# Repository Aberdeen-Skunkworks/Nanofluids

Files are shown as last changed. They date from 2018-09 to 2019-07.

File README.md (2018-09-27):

# Nanofluids

Project background:

Moore's Law is a well-known phenomenon that states that in highly dense integrated circuits (IC) the total number of transistors will approximately double every two years. Thermal management becomes unrealistic as the density of transistors with in the IC increase, thus a new challenge has appeared in heat transfer: cooling of nano-scale devices. A more efficient and compact design of heat exchangers is required for advanced nanoelectronics, and one way this can be achieved is through nanofluid technology. A very large enhancement of the thermal conductivity of a base fluid (i.e. water) can be achieved by the addition of highly conductive solid material in the form of nanoparticles. The mechanics of this enhancement have generally fallen into the classical/continuum bounds given by series and parallel resistances. These bounds are defined by two separate phases of the solid nanoparticles and the liquid medium and the arrangement of the nanoparticles with in the medium. But a small number of experimental result do not fall into these bounds such as helium and hydrogen gas mixtures or the theoretical hard sphere model, which instead exhibit conductivity enhancements above the parallel bounds and dehancement below the series bounds. This project is to explore this phenomena, both experimentally and theoretically, and to attempt to model its effects.

Project Objectives

• Review nanofluids and their history in thermal conductivity enhancement. This includes describing what models have already been used to approximate their behaviour and critically review their applicability.

•	Construct a Transient Heated Wire cell for the testing of liquid and gas mixture thermal conductivities and use this data to explore the anomalous heat transfer in nanofluids and gas mixtures which have similar dimensional properties to nanofluid systems.

• Perform molecular simulations of thermal conduction to confirm if transient effects in the thermal conductivity, possible at small time/length scales, dominate conduction. These simulations may be molecular dynamics simulations using DynamO, or coupled kinetic theory-hydrodynamics simulations using code developed by Craig Moir, a PhD student at Aberdeen

•	Explore new heat exchanger designs which incorporate any time-dependent anomalous phenomena

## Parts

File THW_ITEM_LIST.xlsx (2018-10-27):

ASAD THW ITEM LIST
ITEM | QUANTITY REQUIRED | LINK
PT sensor 1206 | 6 | https://uk.farnell.com/vishay/pts120601b1k00p100/thermistor-pts-ptc-1k-1206/dp/1560921?mckv=sxhpFhfmc_dc|pcrid|148077176083|kword|pts120601b1k00p100|match|p|plid||slid||product||pgrid|15046885808|ptaid|kwd-10806921207|&CMP=KNC-GUK-GEN-SKU-MDC&gclid=CjwKCAjwx7DeBRBJEiwA9MeX_N3hO8ln7X4XWF5Pzf3dMA8ltC6UXv4zSTR2f6gVfCRME1TUpfP6mxoC_D4QAvD_BwE
CAT6 RJ45 Female socket | 5 | https://uk.rs-online.com/web/p/rj45-connectors/7418528/
Potentiometers | 4 | https://uk.rs-online.com/web/p/trimmer-resistors/1442194/
Percise Resistor | 1 | https://uk.rs-online.com/web/p/surface-mount-fixed-resistors/1372749/
Plat Wire | ? | ?
Cu Wire | ? | ?

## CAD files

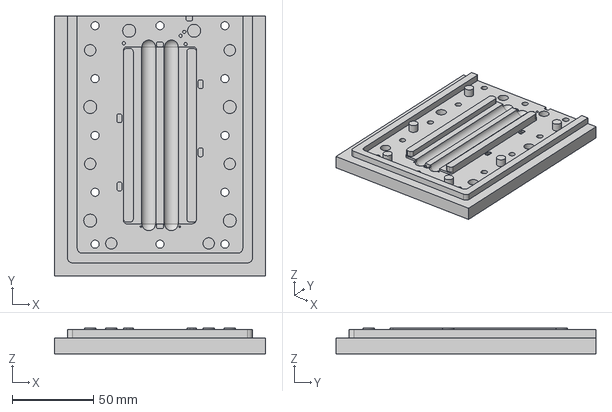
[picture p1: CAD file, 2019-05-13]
THW_Design/CellDesign_1.step
130.0 x 160.0 x 16.0 mm

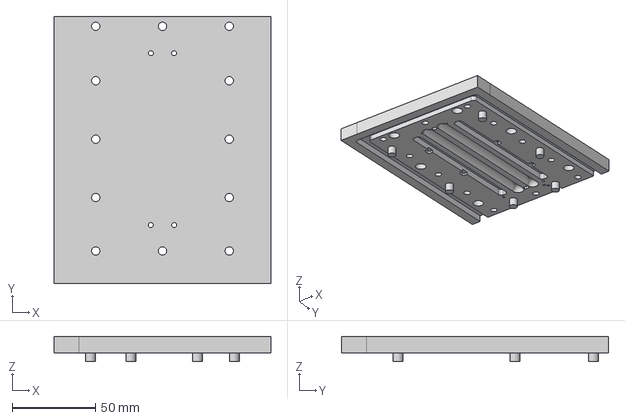
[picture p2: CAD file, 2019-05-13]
THW_Design/CellDesign_2.step
130.0 x 160.0 x 15.0 mm

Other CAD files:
THW_Design/Cell2test.step
THW_Design/test2.step
THW_Design/test.f3d

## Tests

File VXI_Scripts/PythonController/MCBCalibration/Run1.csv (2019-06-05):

Legend:
1-P = | Untitled 1 Process
1-A = | Untitled 1 Ambient
2-P = | Untitled 2 Process
2-A = | Untitled 2 Ambient
Interval: | 10 | Seconds
DataPoint | LogDate | LogTime | 1-P °C | 1-A °C | 2-P °C | 2-A °C
0 | 27/05/2019 | 14:01:39 | 46.8 | 18.0 | 26.8 | 19.5
1 | 27/05/2019 | 14:01:49 | 48.4 | 18.0 | 27.6 | 19.5
2 | 27/05/2019 | 14:01:59 | 49.7 | 18.0 | 28.3 | 19.5
3 | 27/05/2019 | 14:02:09 | 50.9 | 17.9 | 29.0 | 19.5
4 | 27/05/2019 | 14:02:19 | 51.9 | 17.9 | 29.6 | 19.5
5 | 27/05/2019 | 14:02:29 | 52.7 | 17.9 | 30.2 | 19.5
6 | 27/05/2019 | 14:02:39 | 53.5 | 17.9 | 30.8 | 19.5
7 | 27/05/2019 | 14:02:49 | 54.1 | 17.9 | 31.4 | 19.5
8 | 27/05/2019 | 14:02:59 | 54.6 | 17.9 | 32.0 | 19.5
9 | 27/05/2019 | 14:03:09 | 55.1 | 17.9 | 32.5 | 19.5
10 | 27/05/2019 | 14:03:19 | 55.5 | 17.9 | 33.0 | 19.5
11 | 27/05/2019 | 14:03:29 | 55.9 | 17.9 | 33.5 | 19.5
12 | 27/05/2019 | 14:03:39 | 56.2 | 17.9 | 34.0 | 19.4
13 | 27/05/2019 | 14:03:49 | 56.4 | 17.9 | 34.4 | 19.4
14 | 27/05/2019 | 14:03:59 | 56.7 | 17.9 | 34.8 | 19.4
15 | 27/05/2019 | 14:04:09 | 56.9 | 17.9 | 35.3 | 19.4
16 | 27/05/2019 | 14:04:19 | 56.9 | 17.8 | 35.7 | 19.4
17 | 27/05/2019 | 14:04:29 | 57.1 | 17.8 | 36.1 | 19.4
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

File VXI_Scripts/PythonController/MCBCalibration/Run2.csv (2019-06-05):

Legend:
1-P = | Untitled 1 Process
1-A = | Untitled 1 Ambient
2-P = | Untitled 2 Process
2-A = | Untitled 2 Ambient
Interval: | 10 | Seconds
DataPoint | LogDate | LogTime | 1-P °C | 1-A °C | 2-P °C | 2-A °C
0 | 28/05/2019 | 17:16:49 | 21.4 | 17.2 | 21.8 | 18.9
1 | 28/05/2019 | 17:16:59 | 21.4 | 17.2 | 21.8 | 18.9
2 | 28/05/2019 | 17:17:10 | 21.4 | 17.2 | 21.8 | 18.9
3 | 28/05/2019 | 17:17:20 | 21.4 | 17.2 | 21.8 | 18.9
4 | 28/05/2019 | 17:17:30 | 21.4 | 17.2 | 21.8 | 18.9
5 | 28/05/2019 | 17:17:40 | 21.4 | 17.2 | 21.8 | 18.9
6 | 28/05/2019 | 17:17:50 | 21.4 | 17.2 | 21.8 | 18.9
7 | 28/05/2019 | 17:18:00 | 21.5 | 17.2 | 21.8 | 18.9
8 | 28/05/2019 | 17:18:10 | 21.4 | 17.2 | 21.8 | 18.9
9 | 28/05/2019 | 17:18:20 | 21.4 | 17.2 | 21.8 | 18.9
10 | 28/05/2019 | 17:18:30 | 21.4 | 17.2 | 21.8 | 18.9
11 | 28/05/2019 | 17:18:40 | 21.4 | 17.2 | 21.8 | 18.9
12 | 28/05/2019 | 17:18:50 | 21.4 | 17.2 | 21.8 | 18.9
13 | 28/05/2019 | 17:19:00 | 21.4 | 17.2 | 21.9 | 18.9
14 | 28/05/2019 | 17:19:10 | 21.4 | 17.2 | 21.9 | 18.9
15 | 28/05/2019 | 17:19:20 | 21.4 | 17.2 | 21.8 | 18.9
16 | 28/05/2019 | 17:19:30 | 21.4 | 17.2 | 21.8 | 18.9
17 | 28/05/2019 | 17:19:40 | 21.4 | 17.2 | 21.8 | 18.9
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

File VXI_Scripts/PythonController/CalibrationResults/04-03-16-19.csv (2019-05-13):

# | SW | SW (t) | LW | LW (t) | TP (ohm) | Temp Probe (*C) | TP (t) | PT_6 (ohm) | PT_6 (*C) | PT_6 (t) | PT_1 (ohm) | PT_1 (*C) | PT_1 (t) | PT_2 (ohm) | PT_2 (*C) | PT_2 (t) | PT_3 (ohm) | PT_3 (*C) | PT_3 (t) | PT_4 (ohm) | PT_4 (*C) | PT_4 (t) | PT_5 (ohm) | PT_5 (*C) | PT_5 (t)
0 | 38.23242 | 16:19:18.152614 | 56.04883 | 16:19:18.217416 | 107.5488 | 19.371097546592672 | 16:19:18.284237 | 1178.779 | 20.68036856046361 | 16:19:18.351057 | 1179.959 | 20.92157884107316 | 16:19:18.419874 | 1170.195 | 18.921392684463715 | 16:19:18.488691 | 1171.275 | 19.143113850957572 | 16:19:18.555551 | 1233.301 | -312.6102721135922 | 16:19:18.621336 | 1179.891 | 20.907682426459267 | 16:19:18.687160
1 | 38.23047 | 16:19:18.773963 | 56.04492 | 16:19:18.839751 | 107.5449 | 19.361061471522248 | 16:19:18.907570 | 1178.785 | 20.68159541119711 | 16:19:18.974446 | 1179.967 | 20.92321368253006 | 16:19:19.046200 | 1170.203 | 18.923035504072534 | 16:19:19.114018 | 1171.283 | 19.14475578300881 | 16:19:19.182836 | 1233.311 | -312.609460367523 | 16:19:19.249656 | 1179.9 | 20.909521684749542 | 16:19:19.320731
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

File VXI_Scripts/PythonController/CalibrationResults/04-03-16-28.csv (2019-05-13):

# | SW | SW (t) | LW | LW (t) | TP (ohm) | Temp Probe (*C) | TP (t) | PT_6 (ohm) | PT_6 (*C) | PT_6 (t) | PT_1 (ohm) | PT_1 (*C) | PT_1 (t) | PT_2 (ohm) | PT_2 (*C) | PT_2 (t) | PT_3 (ohm) | PT_3 (*C) | PT_3 (t) | PT_4 (ohm) | PT_4 (*C) | PT_4 (t) | PT_5 (ohm) | PT_5 (*C) | PT_5 (t)
0 | 38.24414 | 16:28:49.439085 | 56.07031 | 16:28:49.504885 | 107.5762 | 19.441608229594856 | 16:28:49.573749 | 1179.313 | 20.78954395067271 | 16:28:49.640546 | 1180.377 | 21.006990613046685 | 16:28:49.713327 | 1170.687 | 19.02241385323105 | 16:28:49.784138 | 1171.807 | 19.252288027551632 | 16:28:49.849962 | 1233.842 | -312.5663621480739 | 16:28:49.916783 | 1180.449 | 21.021700899217958 | 16:28:49.986618
1 | 38.24609 | 16:28:50.070376 | 56.06836 | 16:28:50.136197 | 107.5801 | 19.451644538738034 | 16:28:50.206010 | 1179.318 | 20.79056605526184 | 16:28:50.272880 | 1180.389 | 21.009442363919703 | 16:28:50.341647 | 1170.693 | 19.023645665186695 | 16:28:50.408500 | 1171.807 | 19.252288027551632 | 16:28:50.474297 | 1233.855 | -312.565307148045 | 16:28:50.540390 | 1180.453 | 21.022518121923166 | 16:28:50.610962
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

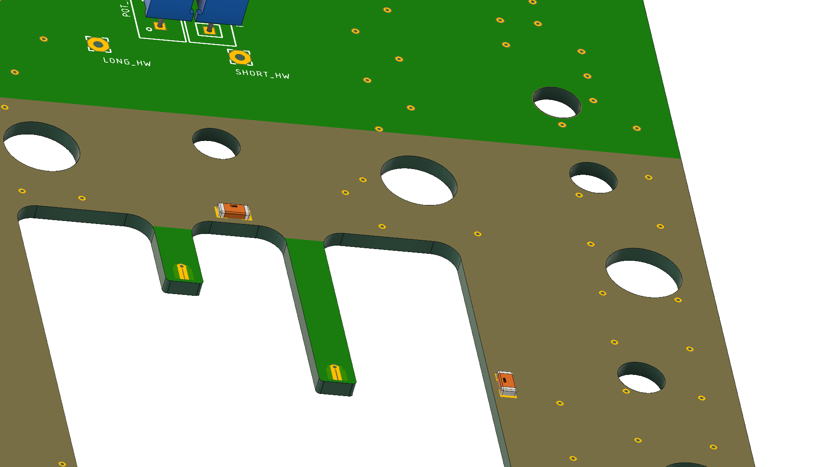
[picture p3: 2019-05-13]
THW_Design/Test v24.png

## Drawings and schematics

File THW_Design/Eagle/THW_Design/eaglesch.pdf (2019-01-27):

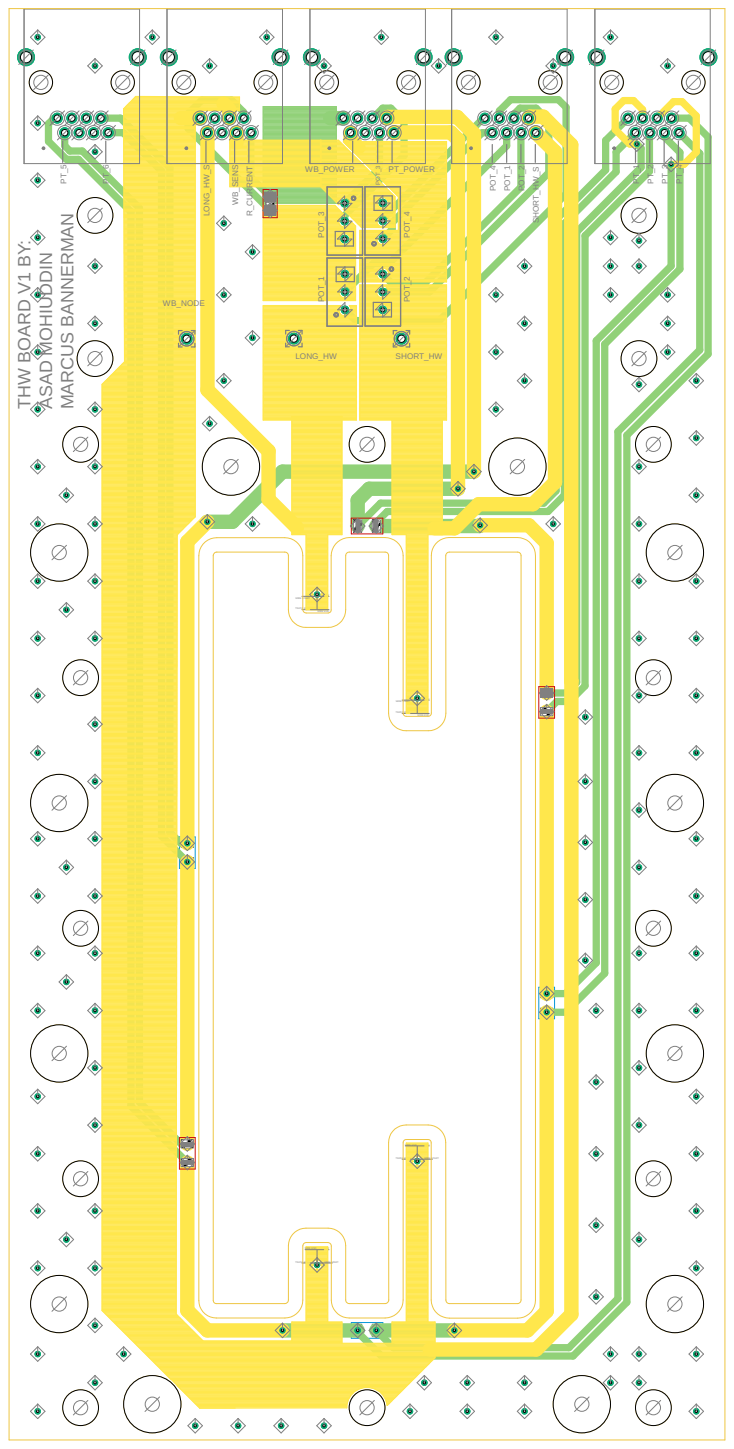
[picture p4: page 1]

WB_NODE

LONG_HW | SHORT_HW

WIRE END WIRE START

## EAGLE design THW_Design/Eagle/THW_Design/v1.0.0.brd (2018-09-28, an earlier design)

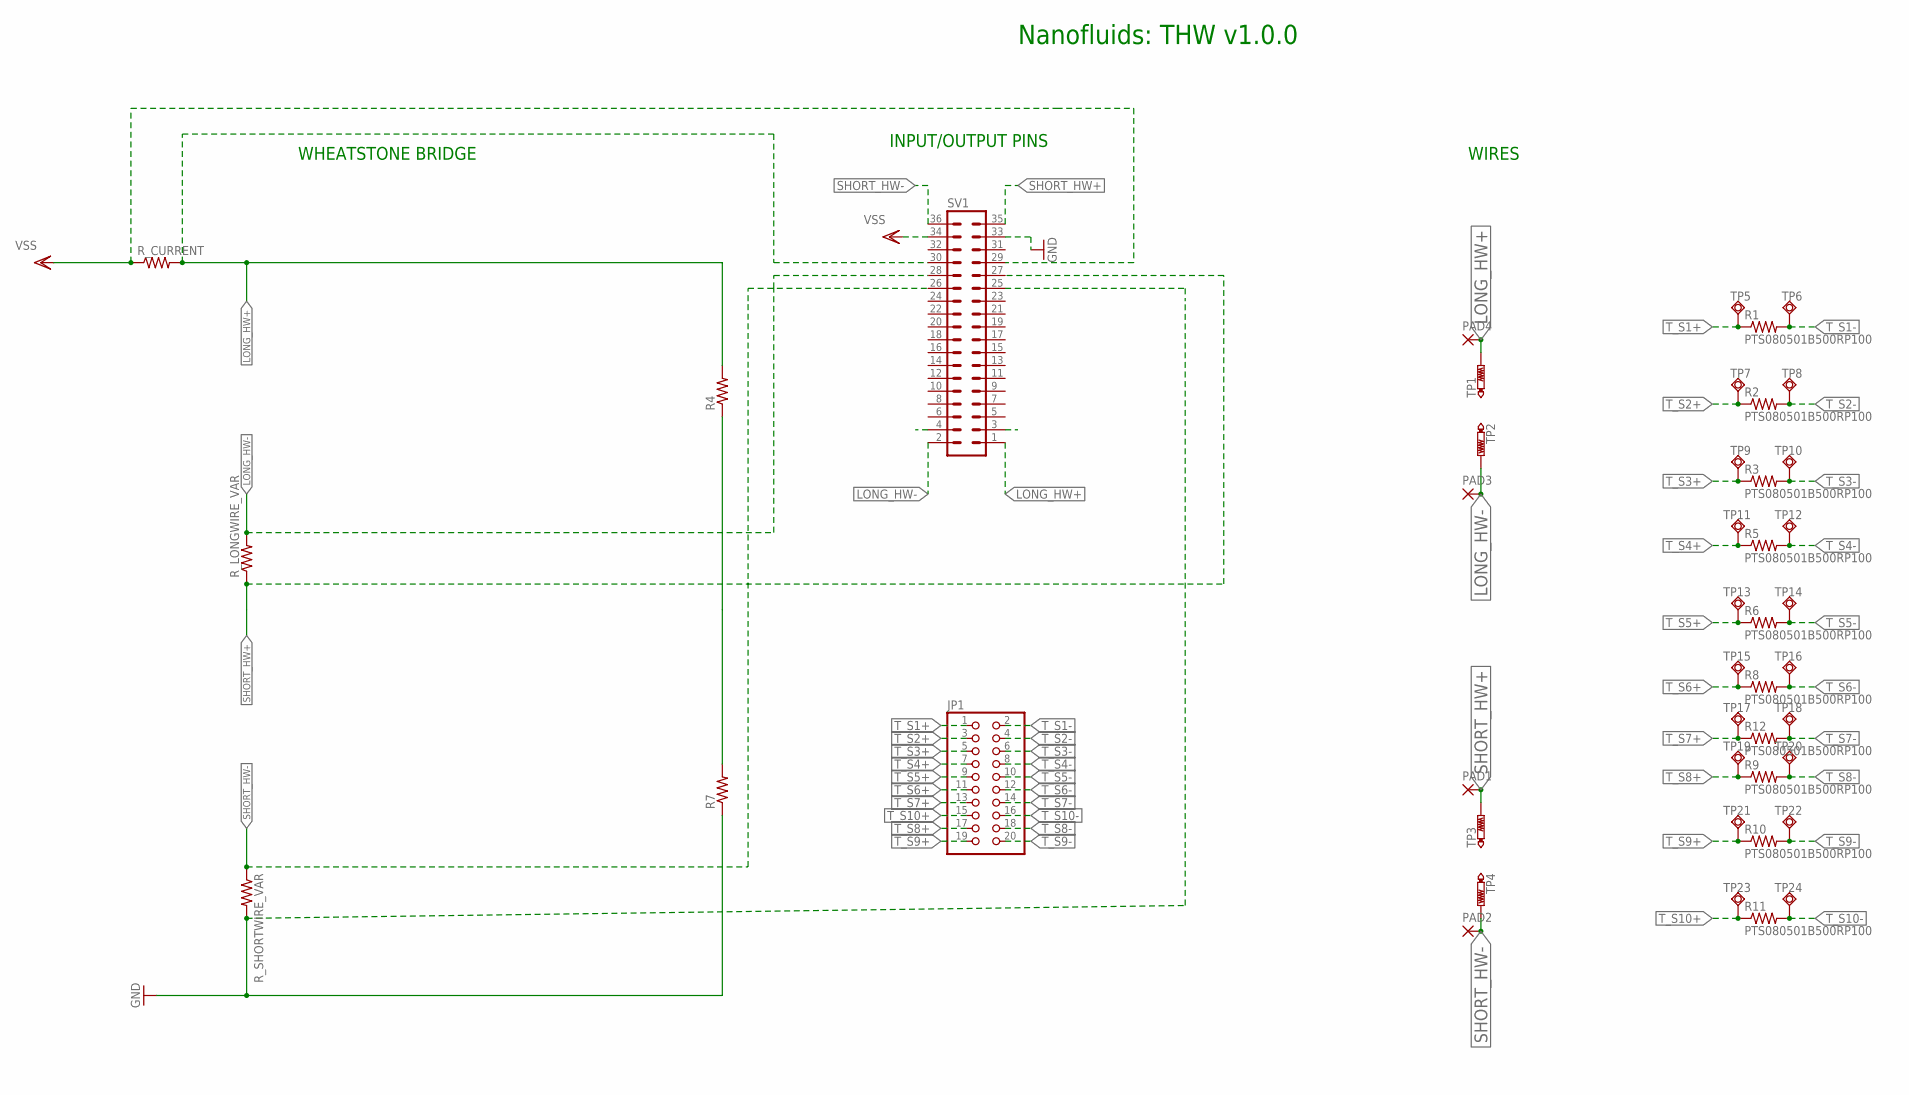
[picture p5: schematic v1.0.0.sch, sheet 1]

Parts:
JP1: PINHD-2X10; 2X10
PAD1, PAD2, PAD3, PAD4: SMD5; SMD2,54-5,08
R1, R2, R3, R5, R6, R8, R9, R10, R11, R12: PTS080501B500RP100; RESC2012X60
R4, R7: R-US_M0805; M0805
R_CURRENT: R-US_M0805; M0805
R_LONGWIRE_VAR: R-US_M0805; M0805
R_SHORTWIRE_VAR: R-US_M0805; M0805
SV1: MA18-2
TP1, TP2, TP3, TP4: PTR1TP20R; TP20R
TP5, TP6, TP7, TP8, TP9, TP10, TP11, TP12, TP13, TP14, TP15, TP16, TP17, TP18, TP19, TP20, TP21, TP22, TP23, TP24: TPSQTP09SQ; TP09SQ

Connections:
GND: R7.1, R_SHORTWIRE_VAR.2, SV1.25, SV1.33
LONG_HW+: PAD4.1, R4.2, R_CURRENT.2, SV1.1, SV1.30, TP1.TP
LONG_HW-: PAD3.1, R_LONGWIRE_VAR.2, SV1.2, SV1.28, TP2.TP
unnamed: R4.1, R7.2
SHORT_HW+: PAD1.1, R_LONGWIRE_VAR.1, SV1.27, SV1.35, TP3.TP
SHORT_HW-: PAD2.1, R_SHORTWIRE_VAR.1, SV1.26, SV1.36, TP4.TP
T_S1+: JP1.1, R1.1, TP5.TP
T_S1-: JP1.2, R1.2, TP6.TP
T_S2+: JP1.3, R2.1, TP7.TP
T_S2-: JP1.4, R2.2, TP8.TP
T_S3+: JP1.5, R3.1, TP9.TP
T_S3-: JP1.6, R3.2, TP10.TP
T_S4+: JP1.7, R5.1, TP11.TP
T_S4-: JP1.8, R5.2, TP12.TP
T_S5+: JP1.9, R6.1, TP13.TP
T_S5-: JP1.10, R6.2, TP14.TP
T_S6+: JP1.11, R8.1, TP15.TP
T_S6-: JP1.12, R8.2, TP16.TP
T_S7+: R12.1, TP17.TP
T_S7-: JP1.14, R12.2, TP18.TP
T_S8+: JP1.17, R9.1, TP19.TP
T_S8-: JP1.18, R9.2, TP20.TP
T_S9+: JP1.19, R10.1, TP21.TP
T_S9-: JP1.20, R10.2, TP22.TP
T_S10+: JP1.15, R11.1, TP23.TP
T_S10-: JP1.16, R11.2, TP24.TP
VSS: R_CURRENT.1, SV1.29, SV1.34

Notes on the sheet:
Nanofluids: THW v1.0.0
WHEATSTONE BRIDGE
WIRES
INPUT/OUTPUT PINS

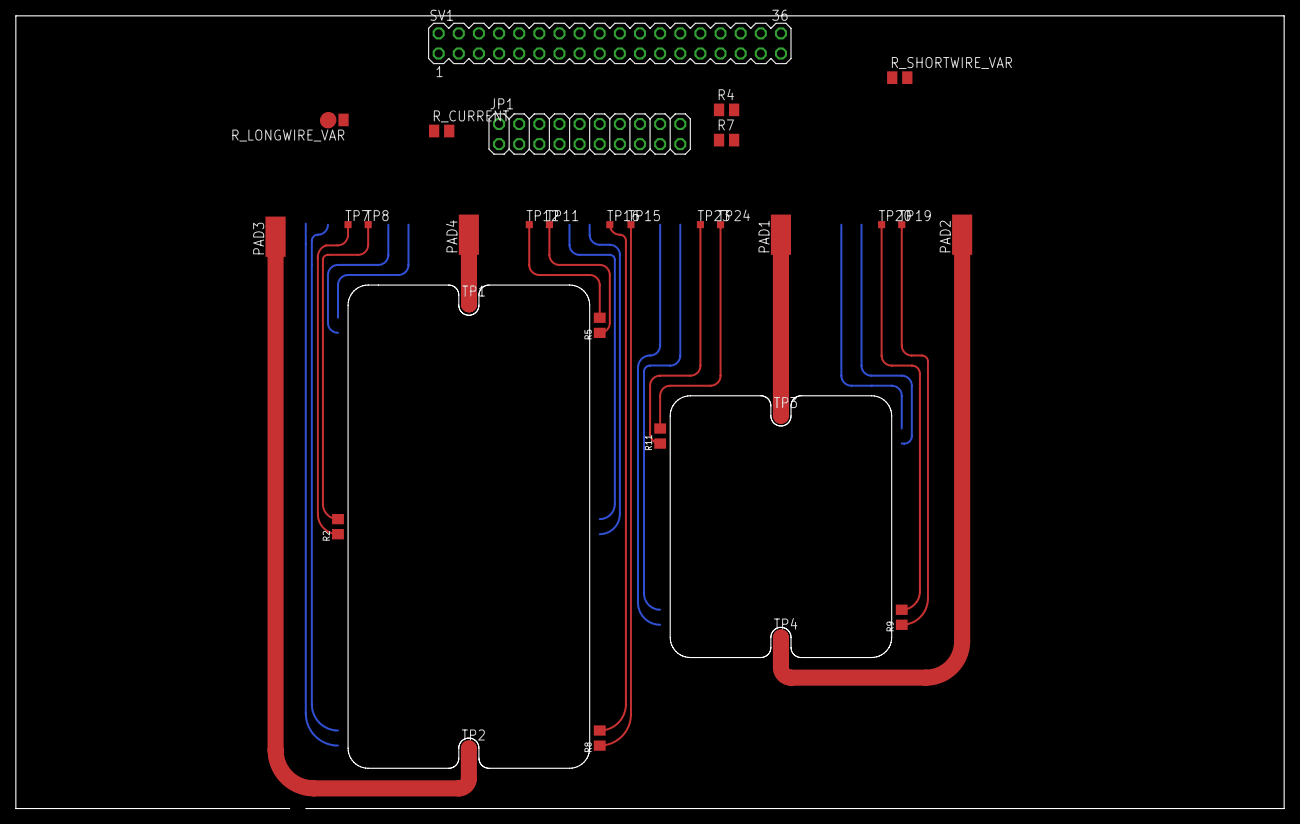
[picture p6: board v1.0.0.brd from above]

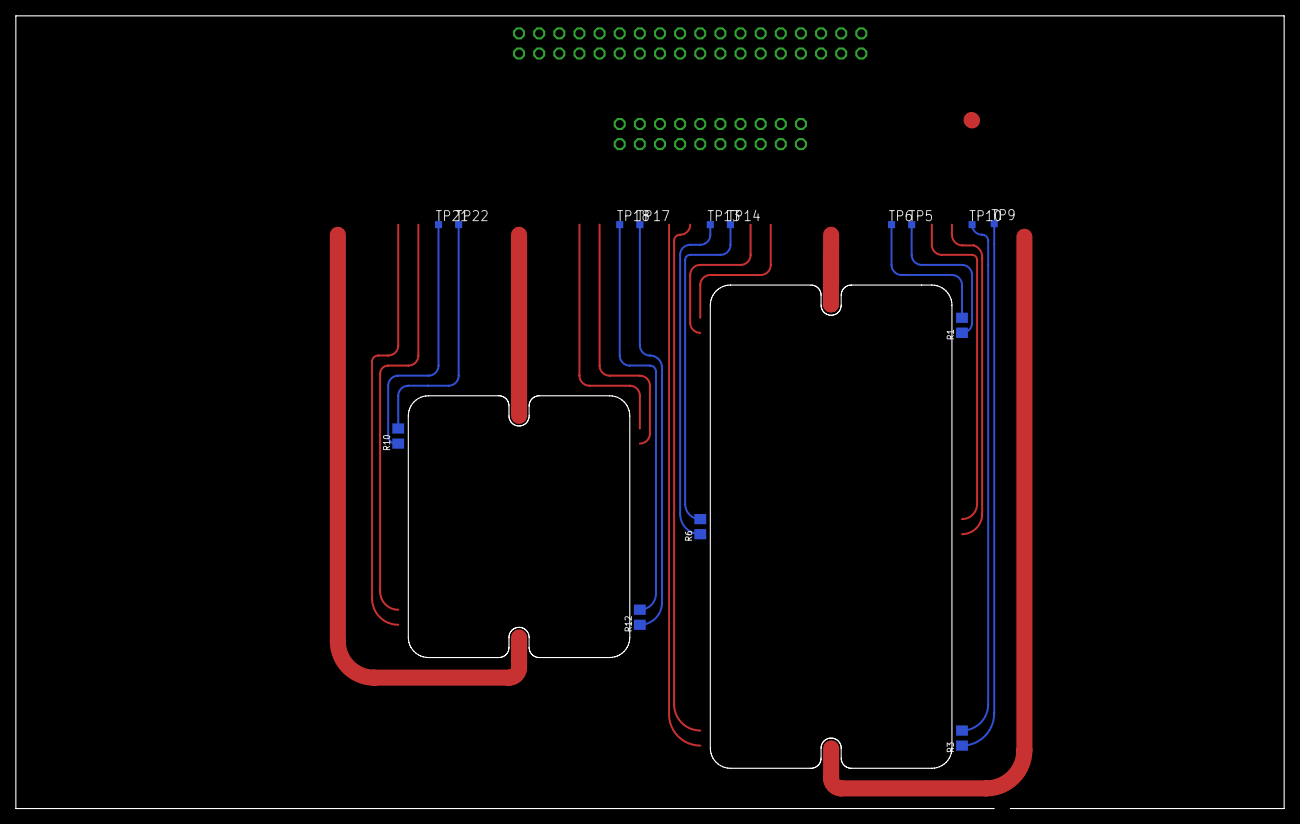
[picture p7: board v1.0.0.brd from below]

Board: 3 copper layers, 160.0 x 100.0 mm, 45 parts (15 on the bottom side), 27 nets.

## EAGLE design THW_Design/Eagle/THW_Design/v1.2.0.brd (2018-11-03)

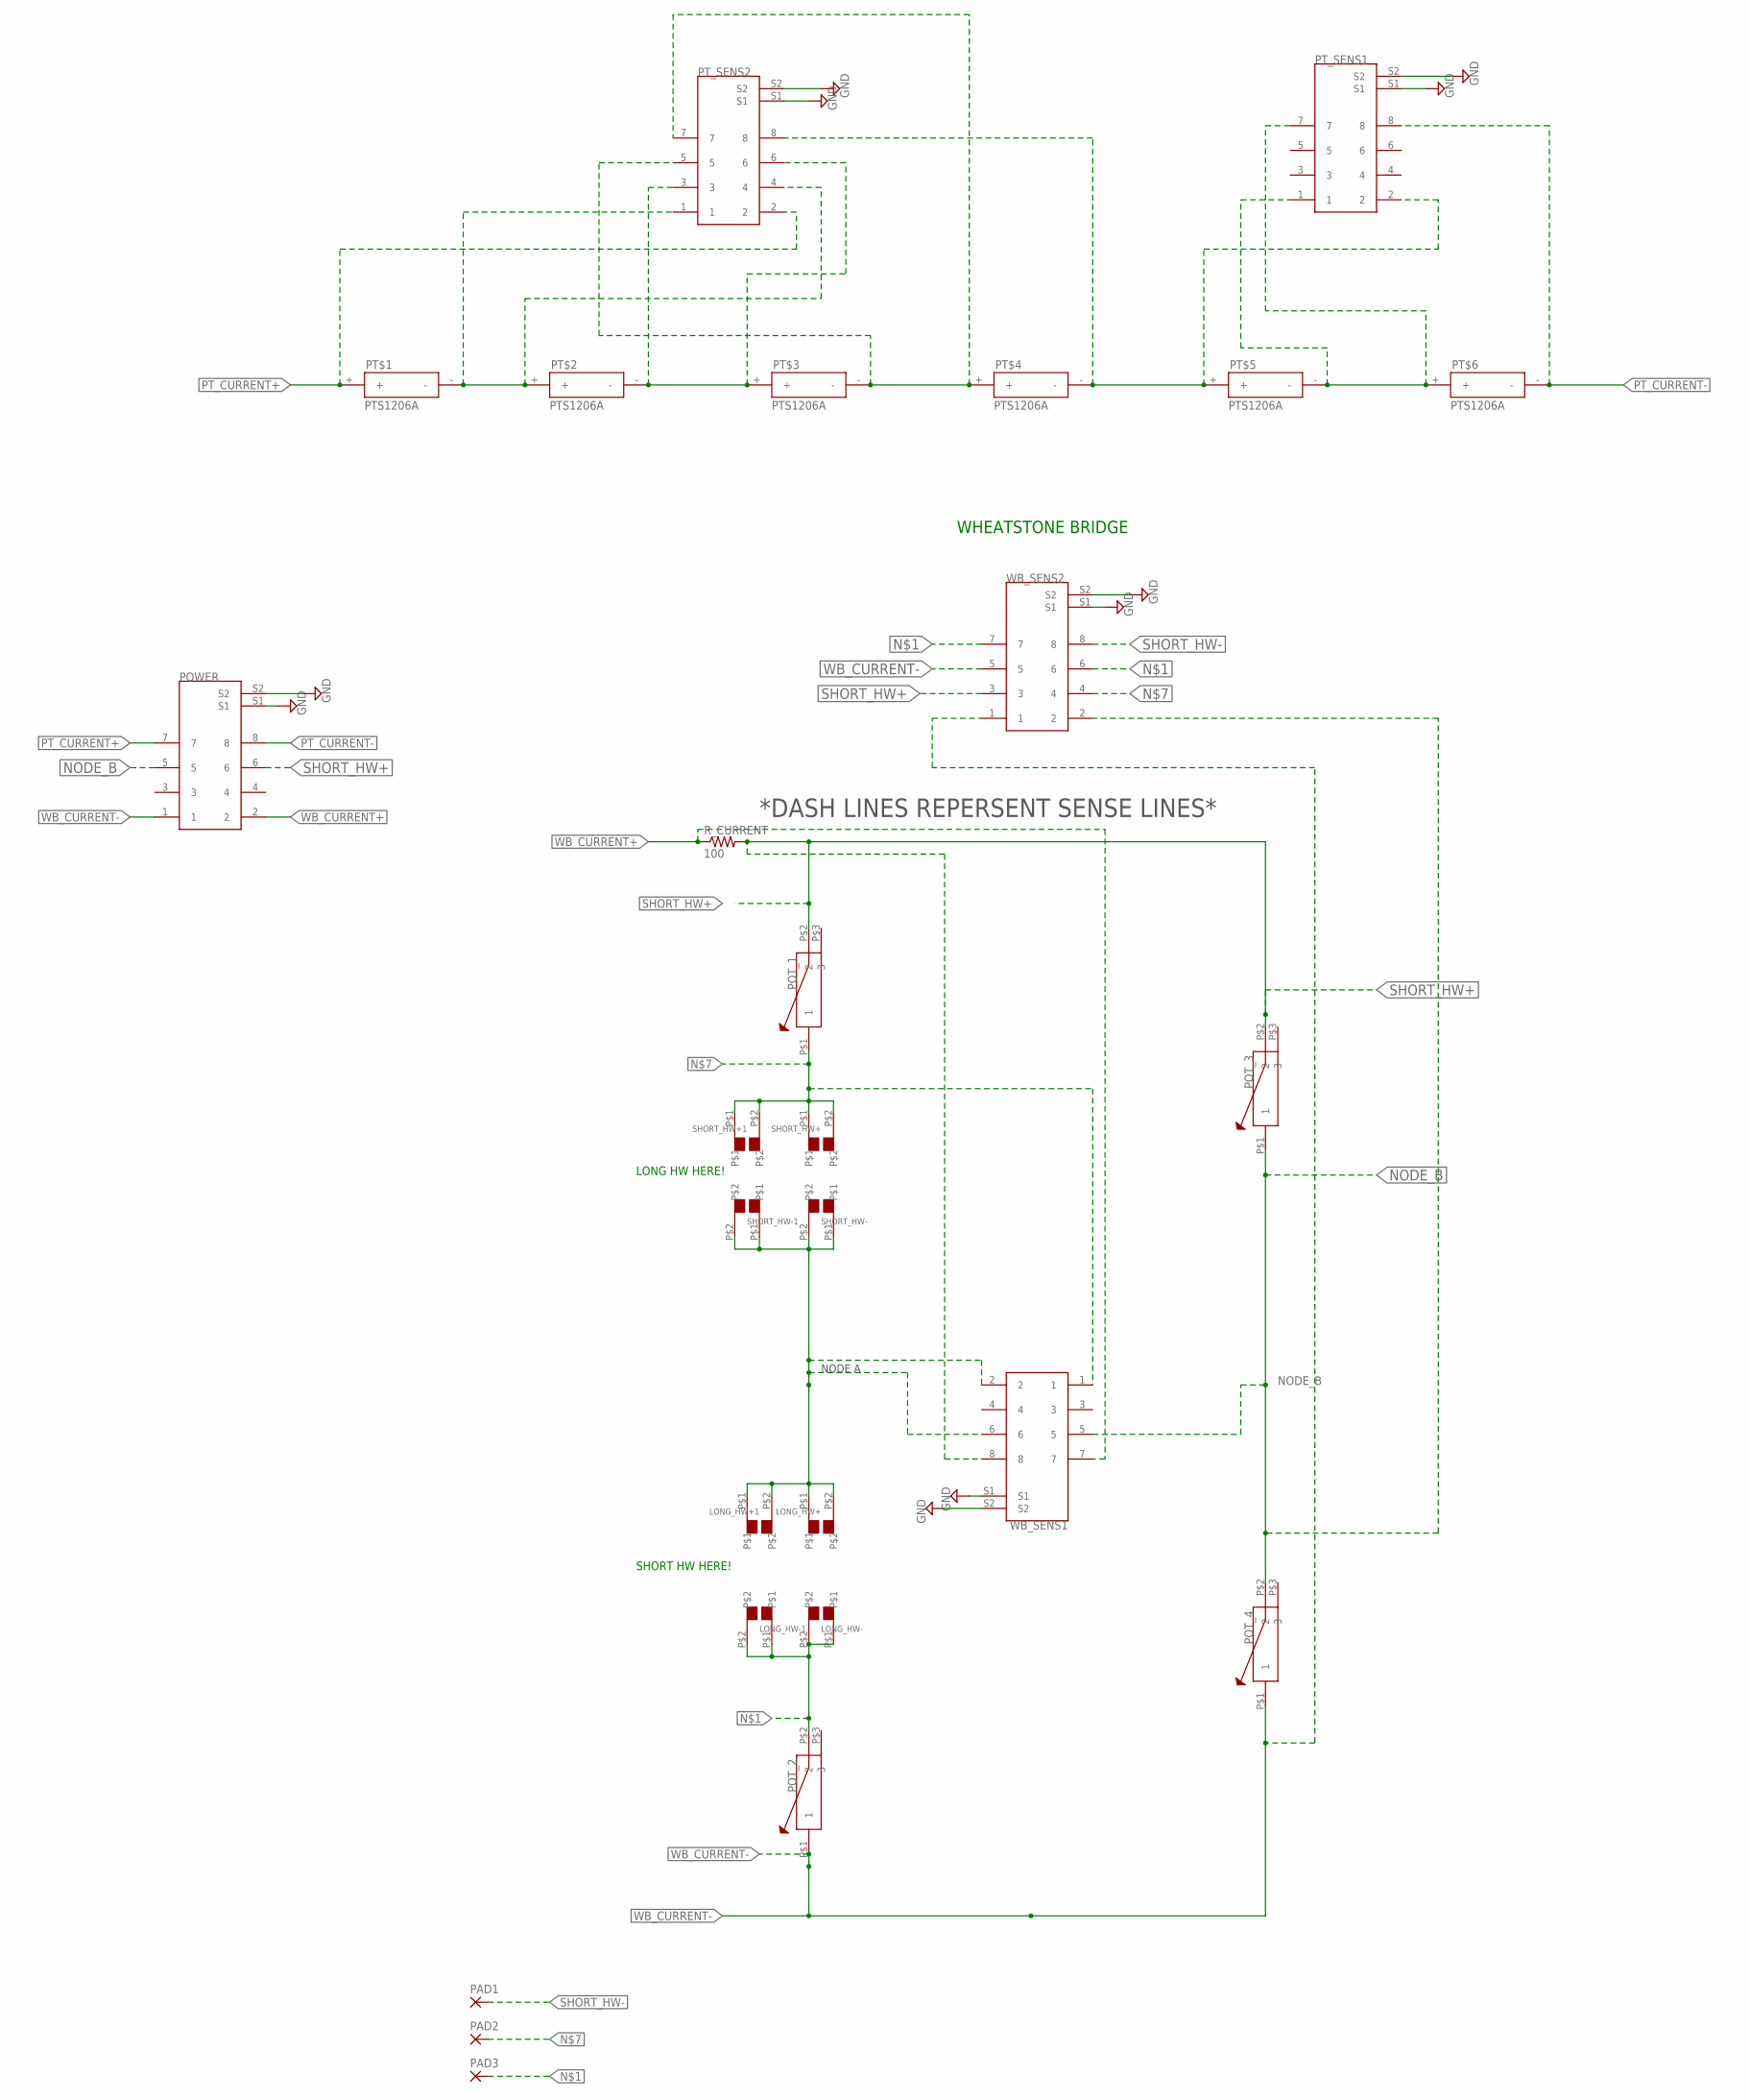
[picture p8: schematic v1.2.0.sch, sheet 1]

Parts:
LONG_HW+, LONG_HW+1: WIREPOINT_1A; WIREPOINT
LONG_HW-, LONG_HW-1: WIREPOINT_1A; WIREPOINT
PAD1, PAD2, PAD3: 2,15/1,0
POT_1, POT_2, POT_3, POT_4: 67WR200LFR$1; 67WR200LF
POWER: RJ45_CONNECTOR; RJ45_CONNNECTOR
PT$1, PT$2, PT$3, PT$4, PT$5, PT$6: PTS1206A; CAPMP3216X166
PT_SENS1, PT_SENS2: RJ45_CONNECTOR; RJ45_CONNNECTOR
R_CURRENT: 100; M0805
SHORT_HW+, SHORT_HW+1: WIREPOINT_1A; WIREPOINT
SHORT_HW-, SHORT_HW-1: WIREPOINT_1A; WIREPOINT
WB_SENS1, WB_SENS2: RJ45_CONNECTOR; RJ45_CONNNECTOR

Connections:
GND: POWER.S1, POWER.S2, PT_SENS1.S1, PT_SENS1.S2, PT_SENS2.S1, PT_SENS2.S2, WB_SENS1.S1, WB_SENS1.S2, WB_SENS2.S1, WB_SENS2.S2
unnamed: LONG_HW-.P$1, LONG_HW-.P$2, LONG_HW-1.P$1, LONG_HW-1.P$2, PAD3.1, POT_2.P$2 (2), WB_SENS2.6, WB_SENS2.7
unnamed: PT$2.-, PT$3.+, PT_SENS2.3, PT_SENS2.6
unnamed: PT$3.-, PT$4.+, PT_SENS2.5, PT_SENS2.7
unnamed: PT$4.-, PT$5.+, PT_SENS1.2, PT_SENS2.8
unnamed: PT$5.-, PT$6.+, PT_SENS1.1, PT_SENS1.7
unnamed: PAD2.1, POT_1.P$1 (1), SHORT_HW+.P$1, SHORT_HW+.P$2, SHORT_HW+1.P$1, SHORT_HW+1.P$2, WB_SENS1.1, WB_SENS2.4
unnamed: PT$1.-, PT$2.+, PT_SENS2.1, PT_SENS2.4
NODE_B: POT_3.P$1 (1), POT_4.P$2 (2), POWER.5, WB_SENS1.5, WB_SENS2.2
PT_CURRENT+: POWER.7, PT$1.+, PT_SENS2.2
PT_CURRENT-: POWER.8, PT$6.-, PT_SENS1.8
SHORT_HW+: POT_1.P$2 (2), POT_3.P$2 (2), POWER.6, R_CURRENT.2, WB_SENS1.8, WB_SENS2.3
SHORT_HW-: LONG_HW+.P$1, LONG_HW+.P$2, LONG_HW+1.P$1, LONG_HW+1.P$2, PAD1.1, SHORT_HW-.P$1, SHORT_HW-.P$2, SHORT_HW-1.P$1, SHORT_HW-1.P$2, WB_SENS1.2, WB_SENS1.6, WB_SENS2.8
WB_CURRENT+: POWER.2, R_CURRENT.1, WB_SENS1.7
WB_CURRENT-: POT_2.P$1 (1), POT_4.P$1 (1), POWER.1, WB_SENS2.1, WB_SENS2.5

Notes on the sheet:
WHEATSTONE BRIDGE
NODE A
*DASH LINES REPERSENT SENSE LINES*
LONG HW HERE!
SHORT HW HERE!

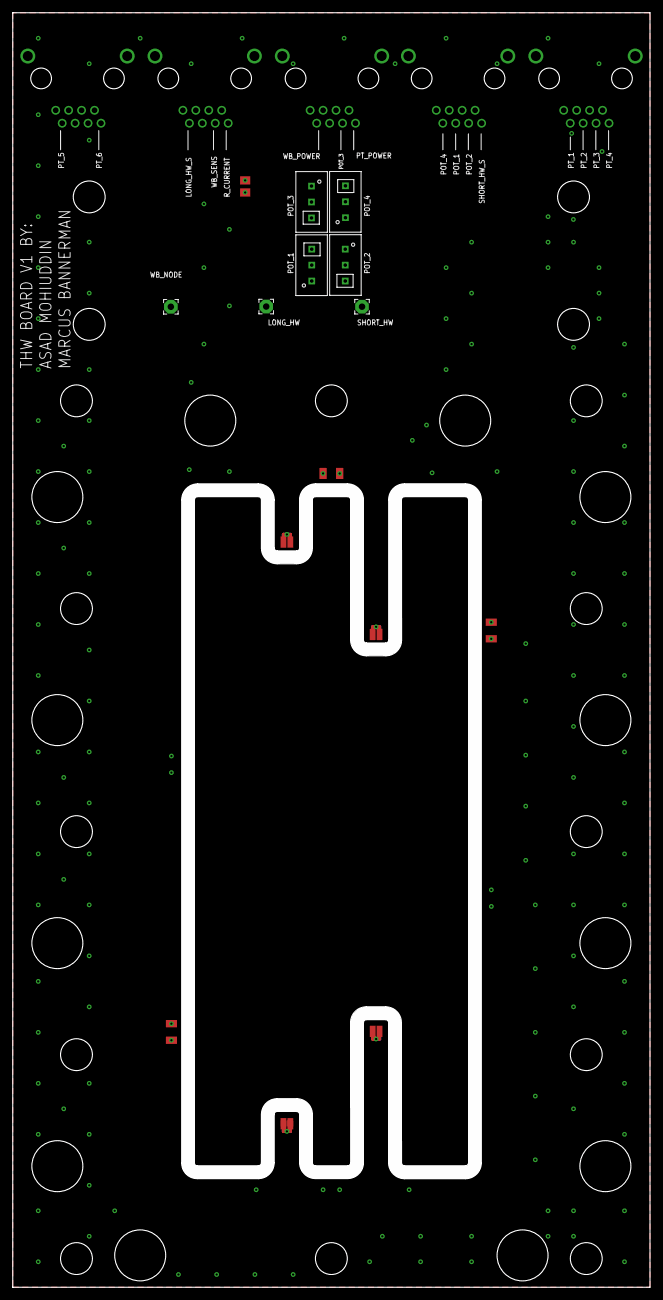
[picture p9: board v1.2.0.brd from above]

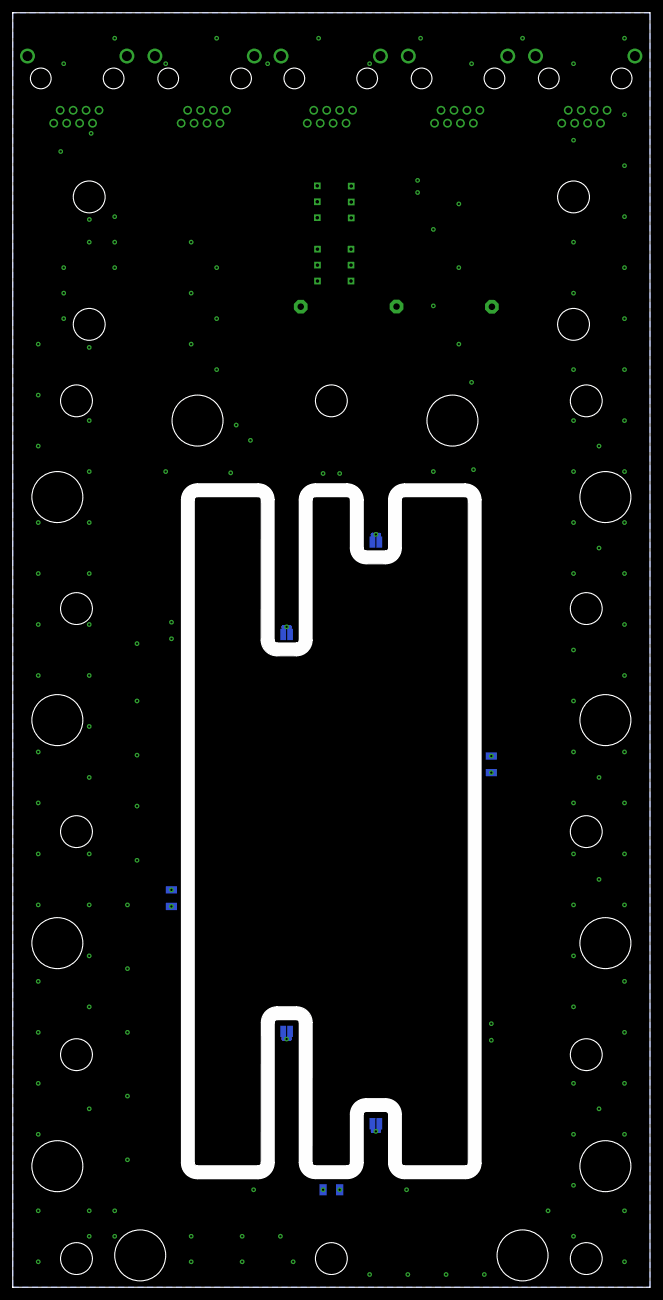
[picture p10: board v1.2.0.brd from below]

Board: 4 copper layers, 100.0 x 200.0 mm, 28 parts (7 on the bottom side), 15 nets.

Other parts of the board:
U$1: AD_LOGO

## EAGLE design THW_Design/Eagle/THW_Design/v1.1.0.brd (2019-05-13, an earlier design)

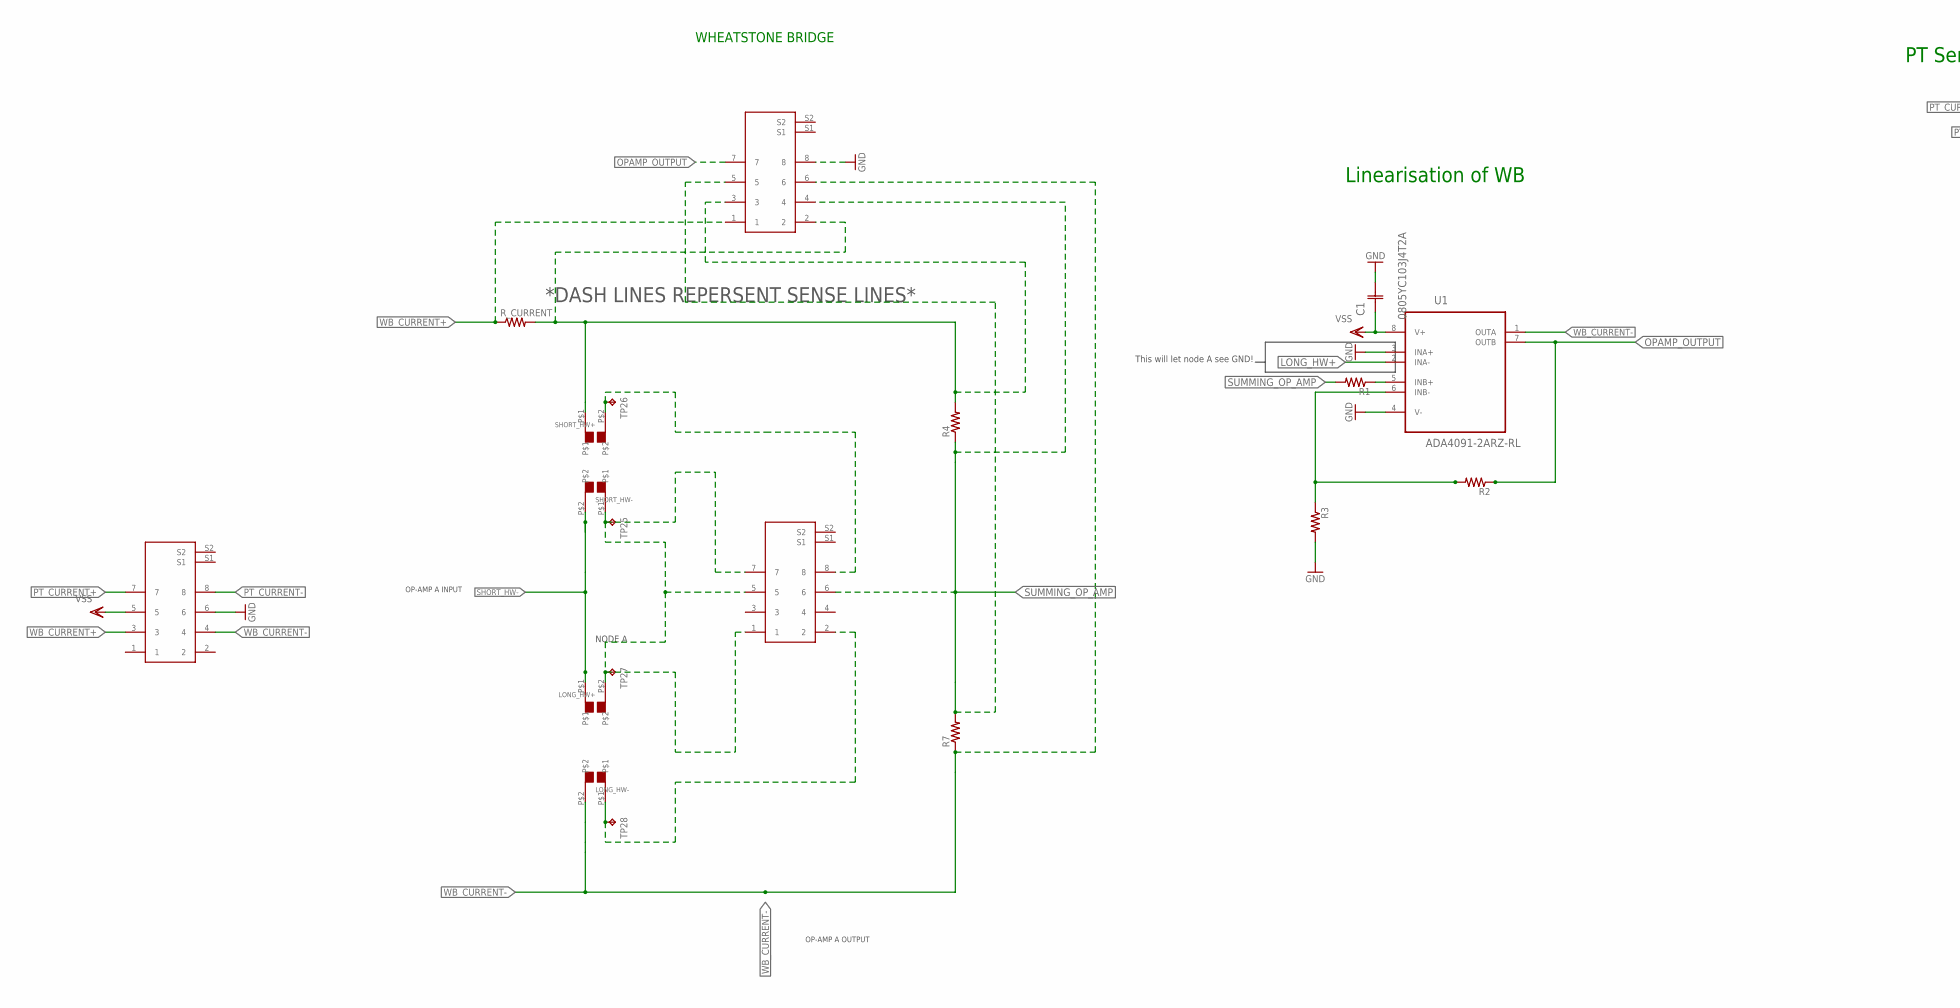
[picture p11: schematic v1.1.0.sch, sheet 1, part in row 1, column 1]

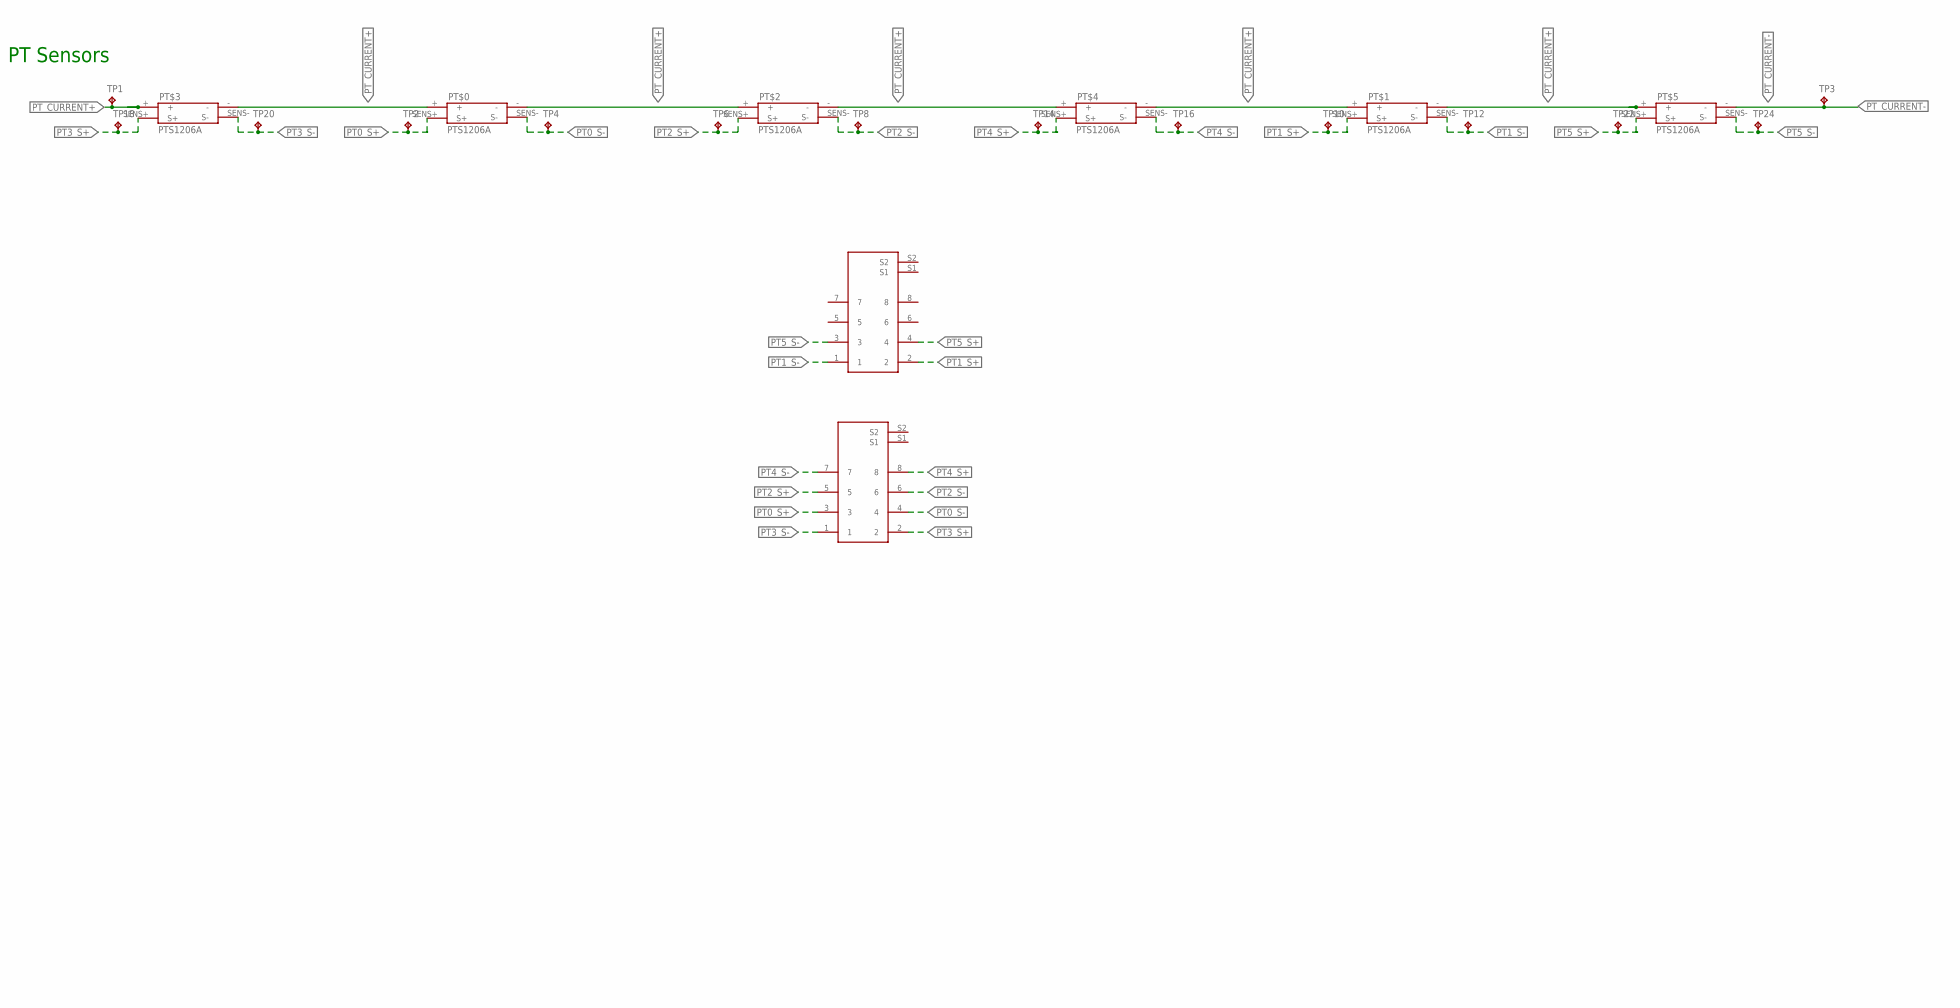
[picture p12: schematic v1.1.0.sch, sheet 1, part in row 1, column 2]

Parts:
C1: 0805YC103J4T2A; CAPC2012X94N
LONG_HW+: WIREPOINT_1A; WIREPOINT
LONG_HW-: WIREPOINT_1A; WIREPOINT
POWER: RJ45_CONNECTOR; RJ45_CONNNECTOR
PT$0, PT$1, PT$2, PT$3, PT$4, PT$5: PTS1206A; CAPMP3216X166
PT_SENS1, PT_SENS2: RJ45_CONNECTOR; RJ45_CONNNECTOR
R1, R2, R3, R4, R7: R-US_M0805; M0805
R_CURRENT: R-US_M0805; M0805
SHORT_HW+: WIREPOINT_1A; WIREPOINT
SHORT_HW-: WIREPOINT_1A; WIREPOINT
TP1, TP2, TP3, TP4, TP6, TP8, TP10, TP12, TP14, TP16, TP18, TP20, TP22, TP24, TP25, TP26, TP27, TP28: TPTP10SQ; TP10SQ
U1: ADA4091-2ARZ-RL; SOIC127P600X175-8N
WB_SENS1, WB_SENS2: RJ45_CONNECTOR; RJ45_CONNNECTOR

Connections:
GND: C1.2 (C2), POWER.6, R3.2, U1.3 (INA+), U1.4 (V-), WB_SENS2.8
LONG_HW+: U1.2 (INA-)
LONG_HW_SENS-: LONG_HW-.P$1, TP28.TP, WB_SENS1.2
unnamed: R1.1, U1.5 (INB+)
unnamed: R2.2, R3.1, U1.6 (INB-)
OPAMP_OUTPUT: R2.1, U1.7 (OUTB), WB_SENS2.7
PT0_S+: PT$0.SENS+ (S+), PT_SENS2.3, TP2.TP
PT0_S-: PT$0.SENS- (S-), PT_SENS2.4, TP4.TP
PT1_S+: PT$1.SENS+ (S+), PT_SENS1.2, TP10.TP
PT1_S-: PT$1.SENS- (S-), PT_SENS1.1, TP12.TP
PT2_S+: PT$2.SENS+ (S+), PT_SENS2.5, TP6.TP
PT2_S-: PT$2.SENS- (S-), PT_SENS2.6, TP8.TP
PT3_S+: PT$3.SENS+ (S+), PT_SENS2.2, TP18.TP
PT3_S-: PT$3.SENS- (S-), PT_SENS2.1, TP20.TP
PT4_S+: PT$4.SENS+ (S+), PT_SENS2.8, TP14.TP
PT4_S-: PT$4.SENS- (S-), PT_SENS2.7, TP16.TP
PT5_S+: PT$5.SENS+ (S+), PT_SENS1.4, TP22.TP
PT5_S-: PT$5.SENS- (S-), PT_SENS1.3, TP24.TP
PT_CURRENT+: POWER.7, PT$0.+, PT$0.-, PT$1.+, PT$1.-, PT$2.+, PT$2.-, PT$3.+, PT$3.-, PT$4.+, PT$4.-, PT$5.+, TP1.TP
PT_CURRENT-: POWER.8, PT$5.-, TP3.TP
SHORT_HW+: R4.2, R_CURRENT.2, SHORT_HW+.P$1, WB_SENS2.2, WB_SENS2.3
SHORT_HW-: LONG_HW+.P$1, SHORT_HW-.P$2
SHORT_HW_SENS+: SHORT_HW+.P$2, TP26.TP, WB_SENS1.8
SHORT_HW_SENS-: LONG_HW+.P$2, SHORT_HW-.P$1, TP25.TP, TP27.TP, WB_SENS1.1, WB_SENS1.5, WB_SENS1.7
SUMMING_OP_AMP: R1.2, R4.1, R7.2, WB_SENS1.6, WB_SENS2.4, WB_SENS2.5
VSS: C1.1 (C1), POWER.5, U1.8 (V+)
WB_CURRENT+: POWER.3, R_CURRENT.1, WB_SENS2.1
WB_CURRENT-: LONG_HW-.P$2, POWER.4, R7.1, U1.1 (OUTA), WB_SENS2.6

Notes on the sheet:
WHEATSTONE BRIDGE
Linearisation of WB
PT Sensors
OP-AMP A INPUT
OP-AMP A OUTPUT
NODE A
This will let node A see GND!
*DASH LINES REPERSENT SENSE LINES*

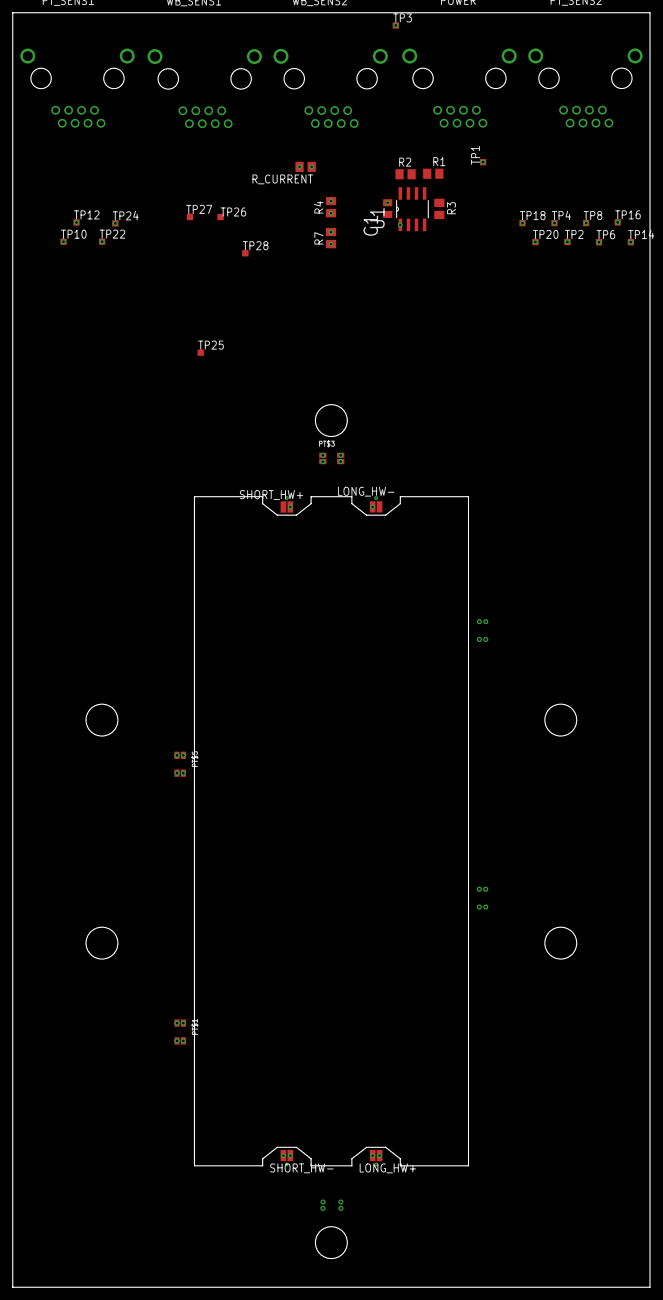
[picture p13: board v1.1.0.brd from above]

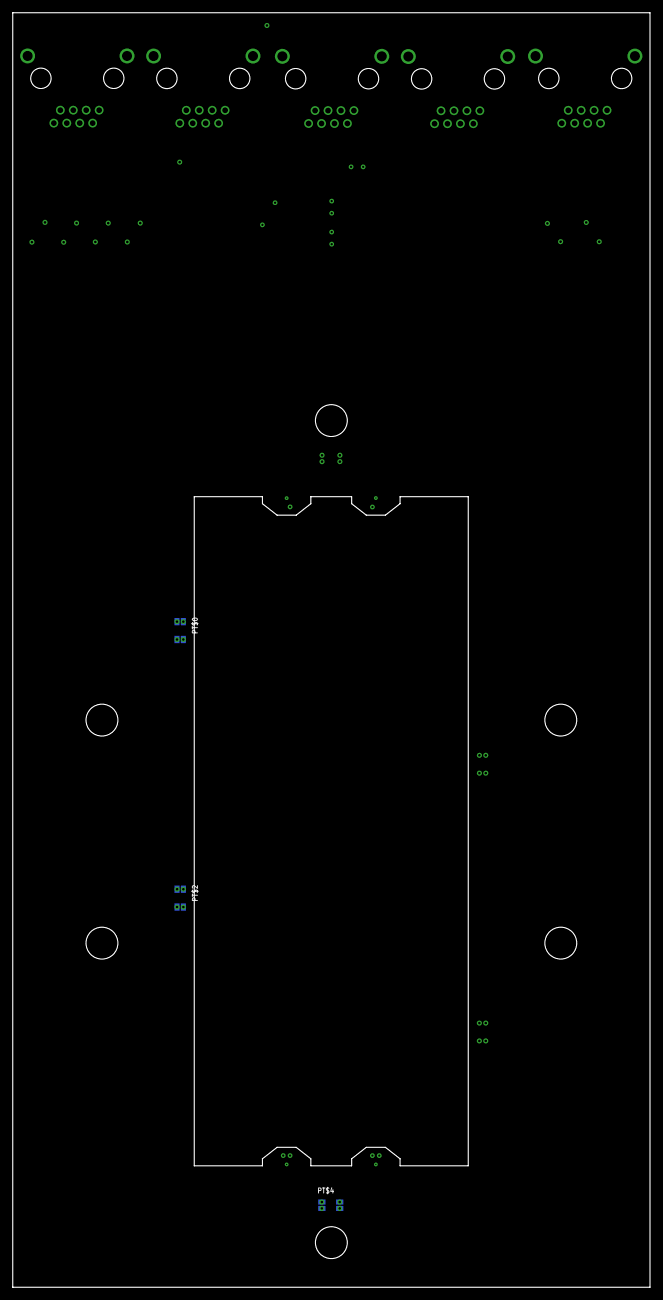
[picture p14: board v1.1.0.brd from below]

Board: 4 copper layers, 100.0 x 200.0 mm, 41 parts (3 on the bottom side), 27 nets.

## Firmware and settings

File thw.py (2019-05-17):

import visa
import serial


class TransientHeatedWire:
    
    COM_CODE = "GPIB0::9::0::INSTR"
    VOLT_METER_CODE = "GPIB0::9::23::INSTR"
    CURRENT_METER_CODE = "GPIB0::9::3::INSTR"
    RELAY_CODE = "GPIB0::9::6::INSTR"
    DA_CODE = "GPIB0::9::4::INSTR"
    
    def __init__(self):
        self.rm = visa.ResourceManager()
        print("Available resources:")
        print(self.rm.list_resources())
        
        self.com = self.rm.open_resource(self.COM_CODE)
        self.Vmeter = self.rm.open_resource(self.VOLT_METER_CODE)
        self.Imeter = self.rm.open_resource(self.CURRENT_METER_CODE)
        self.DA = self.rm.open_resource(self.DA_CODE)
        self.Relay = self.rm.open_resource(self.RELAY_CODE)
        
        #self.ser = serial.Serial("com1")
        
        for p in range(101):
            try:
                self.ser = serial.Serial("com{}".format(p), 9600, timeout=20) 
                print("port: com {} found!".format(p))
                break
            except:
                continue
            
    def __del__(self):
        print("deconstruct")
        #print(self.ser)
        print(self.com)
        self.ser.close()

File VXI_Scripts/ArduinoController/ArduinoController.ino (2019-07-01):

#define ReadTrig 20
#define VMcomplete 35 
#define IMcomplete 36
#define Power 29
#define FET1 27
#define PressurePin 8
#define ledPin 13 //builtin LED

enum State : uint8_t { STAND_BY = 1, IDLE_MODE, WIRE_ON, INIT, RUN, SEND_VDATA, SEND_IDATA, BALANCE };
State THW = STAND_BY;

char rx_byte;

//Microsecond times for events
const unsigned long PowerTimeStart = 1000;
const unsigned long PowerTime = 10000000;

//Number of readings to take
const unsigned long numReadings = 10000;

unsigned long VMtime[numReadings];
unsigned long IMtime[numReadings];
unsigned long VMcounter;
unsigned long IMcounter;

volatile unsigned long runStartMicros;
volatile int VMTrigCheck;
volatile unsigned int VMTrigMicros;
volatile int IMTrigCheck;
volatile unsigned int IMTrigMicros;


int PowerCheck = 0;

float Voltage;
float Signal;
float Pressure;

void setup() {
  Serial.begin(9600);
  pinMode(ReadTrig, OUTPUT);
  pinMode(Power, OUTPUT);
  pinMode(VMcomplete, INPUT);
  pinMode(IMcomplete, INPUT);
  attachInterrupt(VMcomplete, ISR_VMTrigTiming, FALLING);
  attachInterrupt(IMcomplete, ISR_IMTrigTiming, FALLING);
}

void loop() {

  if (Serial.available() > 0) {
    rx_byte = Serial.read();
    Serial.clear();

  if ((rx_byte == '0')) {
      THW = STAND_BY;
   }else if ((rx_byte == '1')) {
      THW = INIT;
   }else if ((rx_byte == '2')) {
      THW = SEND_VDATA;
   }else if ((rx_byte == '3')) {
      THW = BALANCE;
   }else if ((rx_byte == '4')) {
      THW = WIRE_ON;
   }else if ((rx_byte == '5')) {
      THW = SEND_IDATA;
   }else {
      Serial.print(rx_byte);
      Serial.println(" is not a valid command.");
   }
  }

   switch(THW){
    case IDLE_MODE:
      break;
    case WIRE_ON:
      digitalWrite(Power, HIGH);
      digitalWrite(FET1, LOW);    
      break;
    case STAND_BY:
      digitalWrite(ledPin, HIGH);
      digitalWrite(ReadTrig, HIGH);
      digitalWrite(Power, LOW);
      digitalWrite(FET1, HIGH);
      THW=IDLE_MODE;
      break;
    case INIT:
      PowerCheck = 0;
      VMTrigCheck = 0;
      IMTrigCheck = 0;
      VMcounter = 0;
      IMcounter = 0;
      THW = RUN;
      runStartMicros = micros();
      //No break, just carry on with the run!
    case RUN: //Also running while in start mode.
    {
      unsigned long currTime = micros() - runStartMicros;
      if (currTime <= (PowerTime + PowerTimeStart)){
        digitalWrite(ReadTrig, LOW);
        digitalWrite(ledPin, LOW);
        if (currTime >= PowerTimeStart){
          digitalWrite(FET1, LOW);
          digitalWrite(Power, HIGH);
        }
      } else if (currTime > (PowerTime + PowerTimeStart) && PowerCheck == 0){
        digitalWrite(Power, LOW);
        PowerCheck = 1;
        Serial.println("Break");
      }

      if (VMTrigCheck == 1){
        VMtime[VMcounter++] = VMTrigMicros - runStartMicros;
        VMTrigCheck = 0;
      } 

      if (IMTrigCheck == 1){
        IMtime[IMcounter++] = IMTrigMicros - runStartMicros;
        IMTrigCheck = 0;
      } 

      if (currTime > PowerTime){
        THW = STAND_BY;
        Serial.println("PowerTimeStart");
        Serial.println(PowerTimeStart);
        Serial.println("PowerTime");
        Serial.println(PowerTime);
      }
      break;
    }
    case SEND_VDATA:
      Serial.println("VMReadings");
      Serial.println(VMcounter);

      Serial.println("VMtime");
      for (unsigned int n = 0; n < VMcounter; n++){
        delay(1); //Delay to allow python time to process (so as to not run out of input buffer)
        Serial.println(VMtime[n]);
      }
      THW = STAND_BY;
      break;
    case SEND_IDATA:
      Serial.println("IMReadings");
      Serial.println(IMcounter);
      Serial.println("IMtime");
      for (unsigned int i = 0; i< IMcounter; i++){
        delay(1); //Delay to allow python time to process (so as to not run out of input buffer)
        Serial.println(IMtime[i]);
      }
      THW = STAND_BY;
      break;
    case BALANCE:
      digitalWrite(Power, HIGH);
      THW=IDLE_MODE;
      break;
   }
}

void ISR_VMTrigTiming(){
  VMTrigMicros = micros();
  VMTrigCheck = 1;
}

void ISR_IMTrigTiming(){
  IMTrigMicros = micros();
  IMTrigCheck = 1;
}
      //Pressure Transducer
      //Serial.println(analogRead(PressurePin));
      //Signal = analogRead(PressurePin);
      //Voltage = (Signal/(1024))*3.3;
      //Serial.println(Voltage);
      //Pressure = ((Voltage/5) - 0.04)/0.0012858;
      //Serial.println(Pressure);
      //delay(200);
      //break;

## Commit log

2018-09-28 added PCB v1.0.0
    [THW_Schematic_v1.0.0.brd, THW_Schematic_v1.0.0.sch]
2018-10-02 changed version
    [v1.0.0.brd, v1.0.0.sch]
2018-10-02 resistance on traces
    [v1.1.0.brd]
2018-10-11 new version
    [v1.1.0.brd, v1.1.0.sch]
2018-10-12 adding one current source to PT sensors
    [v1.1.0.brd, v1.1.0.sch]
2018-10-17 new traces
    [v1.2.0.brd, v1.2.0.sch]
2018-10-17 Some polygon work for Asad
    [v1.2.0.brd]
2018-10-17 finish routing pt sensors tomorrow
    [v1.2.0.brd, v1.2.0.sch]
2018-10-18 added the cool logo
    [v1.2.0.brd]
2018-10-21 peeled back solder mask for cell contacts
    [v1.2.0.brd]
2018-10-22 Minor changes to design and logo package
    [THW_ITEM_LIST.xlsx, v1.2.0.brd]
2018-10-26 moving to PC, eagle getting laggy
    [v1.2.0.brd]
2018-10-27 updated shopping list
    [THW_ITEM_LIST.xlsx]
2018-10-27 V1 THW DONE :)!
    [v1.2.0.brd]
2018-10-29 4-wire sense
    [v1.2.0.brd, v1.2.0.sch]
2018-11-03 added silkscreens where needed, stiching via's need to be worked
    [v1.2.0.brd, v1.2.0.sch]
2018-11-03 stiching via
    [v1.2.0.brd]
2018-11-03 More work
    [v1.2.0.brd, v1.2.0.sch]
2018-11-03 fix sheild pin
    [v1.2.0.brd, v1.2.0.sch]
2018-11-03 removed tNames
    [v1.2.0.brd]
2018-11-03 Updated the board
    [v1.2.0.brd]
2018-11-03 Fixed thermals on bottom sheild, and the wire supports
    [v1.2.0.brd, v1.2.0.sch]
2018-11-03 updated rj45 dimensions
    [v1.2.0.brd, v1.2.0.sch]
2018-11-03 More fixes
    [v1.2.0.brd, v1.2.0.sch]
2019-05-13 new commit
    [04-03-16-19.csv, 04-03-16-28.csv, 04-03-20-19.csv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]
2019-05-13 deleting files
    [PlotDigitiser.csv, PlotDigitiser2.csv, PlotDigitiser3.csv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]
2019-05-17 Fixed UI, improved experiment speed, uses MOSFETS
    [05-14-14-21.csv]
2019-05-17 Removing temporary files, also working on single wire script
2019-05-21 Figured out remote resetting of the rack and better error checking
    [THW.py]
2019-05-22 Trying to get the relay working, but this commit has broken RTD probe reads
    [THW.py]
2019-05-23 RTD now working again, also added checking the current sense resistor resistance
2019-05-23 Added instrument classes to provide better error detection
    [THW.py]
2019-05-24 Added more error checking, and now working on the relay mux class
    [THW.py]
2019-05-25 More work, gotten the relay mux to be a lot cleaner/extendable
2019-05-27 Have added data logging for calibration
2019-06-05 Fixed an issue with the new reset_rack and error checking
    [Run1.csv, Run2.csv]
2019-06-05 Now performing transient heated wire tests
2019-06-05 Now the THW test collects 6k samples at 13kHz, with accurate current metering
    [current.csv, voltage.csv]
2019-06-06 Fully working setup! Now just need to interpret I hope!
    [current.csv, voltage.csv]
2019-06-13 Working calibration on the wires and some single wire tests
